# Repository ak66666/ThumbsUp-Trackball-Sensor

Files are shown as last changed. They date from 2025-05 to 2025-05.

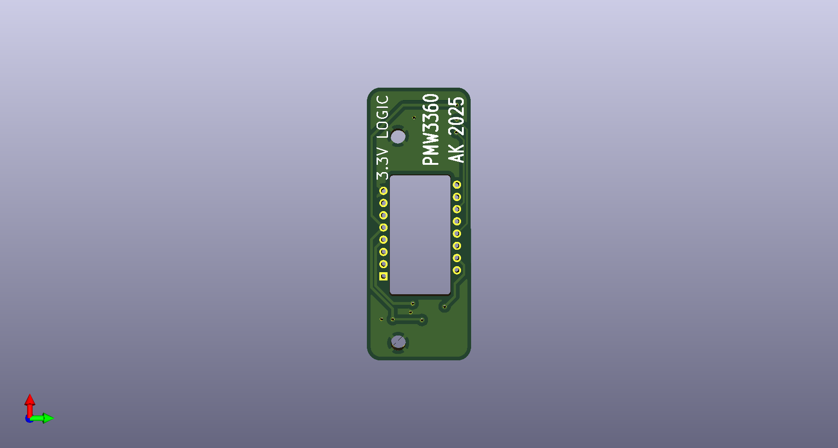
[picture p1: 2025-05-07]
Pictures/PMW3360 Back View.png

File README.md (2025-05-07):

# PMW3360 breakout board

# A clone of https://github.com/jfedor2/pmw3360-breakout

Changes inlclude:
- Layout modified to make the board narrower.
- Connector for a 12 line flexible cable replaced the pin headers.
The rest is practically the same.

This repository contains PCB design files for a breakout board for the PMW3360 optical mouse sensor.

The board doesn't do any level shifting so it only works with 3.3V logic.

The dimensions of the board are 40mm x 15mm, the mounting holes are for M2 screws.

The files in the [fabrication](fabrication) folder can be used to order this board from JLCPCB with SMT assembly. 
The board you get includes everything except the actual sensor. 
If some of the specific components are out of stock, try to find an equivalent with the same package and parameters.

The sensor chip should be soldered on the top side (the side where all the other components are). 
The dot marks pin 1. The optic goes on the bottom side.

//TODO a render of the PCB

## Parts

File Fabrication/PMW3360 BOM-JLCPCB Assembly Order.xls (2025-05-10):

JLCPCB BOM Tool - BOM Matching
BOM name：PMW3360 BOM-JLCPCB Assembly Order.xlsx |  |  | Download Time：2025-05-09 08:33:58 |  |  |  | * Our matching results are updated in real-time, but stock and prices may change. If it's been over 24 hours, please re-match before placing your order.
PCB Assembled Qty：5 |  |  | Est. Total Price：1.0211
Your BOM |  |  |  |  | Matched Parts |  |  |  |  |  |  | Order Information
Top Designator | Bottom Designator | Comment | Footprint | JLCPCB Part # | Matches | Part # | Manufacturer | Footprint | Description | Category | Warning | JLCPCB Part # | Product link | Lib Type | Qty | Source | Total Price ($)
C1 |  | 0.1u | C_0603_1608Metric |  | Select by System | CC0603KRX7R9BB104 | YAGEO | 0603 | 50V 100nF X7R ±10% 0603 Multilayer Ceramic Capacitors MLCC - SMD/SMT ROHS | Multilayer Ceramic Capacitors MLCC - SMD/SMT |  | C14663 | https://jlcpcb.com/partdetail/YAGEO-CC0603KRX7R9BB104/C14663 | Basic | 5 | 5 JLCPCB | 0.012
C2 |  | 1u | C_0603_1608Metric |  | Select by System | CL10A105KB8NNNC | Samsung Electro-Mechanics | 0603 | 50V 1uF X5R ±10% 0603 Multilayer Ceramic Capacitors MLCC - SMD/SMT ROHS | Multilayer Ceramic Capacitors MLCC - SMD/SMT |  | C15849 | https://jlcpcb.com/partdetail/16531-CL10A105KB8NNNC/C15849 | Basic | 5 | 5 JLCPCB | 0.0255
C3 |  | 4.7u | C_0603_1608Metric |  | Select by System | CL10A475KO8NNNC | Samsung Electro-Mechanics | 0603 | 16V 4.7uF X5R ±10% 0603 Multilayer Ceramic Capacitors MLCC - SMD/SMT ROHS | Multilayer Ceramic Capacitors MLCC - SMD/SMT |  | C19666 | https://jlcpcb.com/partdetail/20375-CL10A475KO8NNNC/C19666 | Basic | 5 | 5 JLCPCB | 0.0565
R1 |  | 39 | R_0603_1608Metric |  | Select by System | RC0603FR-0739RL | YAGEO | 0603 | 100mW Thick Film Resistors 75V ±100ppm/℃ ±1% 39Ω 0603 Chip Resistor - Surface Mount ROHS | Chip Resistor - Surface Mount |  | C137733 | https://jlcpcb.com/partdetail/YAGEO-RC0603FR0739RL/C137733 | Extended | 20 | 20 JLCPCB | 0.024
R2 |  | 10k | R_0603_1608Metric |  | Select by System | 0603WAF1002T5E | UNI-ROYAL(Uniroyal Elec) | 0603 | 100mW Thick Film Resistors 75V ±100ppm/℃ ±1% 10kΩ 0603 Chip Resistor - Surface Mount ROHS | Chip Resistor - Surface Mount |  | C25804 | https://jlcpcb.com/partdetail/26547-0603WAF1002T5E/C25804 | Basic | 5 | 5 JLCPCB | 0.005
U2 |  | TCR2EF19 | SOT-23-5 |  | Select by Customer | TLV70018DDCR | Texas Instruments | SOT-23-5 | 68dB@(1kHz) 200mA Fixed 1.8V Positive electrode 5.5V SOT-23-5 Voltage Regulators - Linear, Low Drop Out (LDO) Regulators ROHS | Voltage Regulators - Linear, Low Drop Out (LDO) Regulators | 1.The comment (TLV70018DDCR) of this part does not match the one (TCR2EF19) provided in your BOM. Please confirm; | C79924 | https://jlcpcb.com/partdetail/TexasInstruments-TLV70018DDCR/C79924 | Extended | 7 | 7 JLCPCB | 0.8981

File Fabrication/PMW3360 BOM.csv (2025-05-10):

Designator | Footprint | Quantity | Designation | LCSC
U2 | SOT-23-5 | 1 | TCR2EF19
R2 | R_0603_1608Metric | 1 | 10k | C25804
R1 | R_0603_1608Metric | 1 | 39 | C137733
C3 | C_0603_1608Metric | 1 | 4.7u | C19666
C2 | C_0603_1608Metric | 1 | 1u | C15849
C1 | C_0603_1608Metric | 1 | 0.1u | C14663

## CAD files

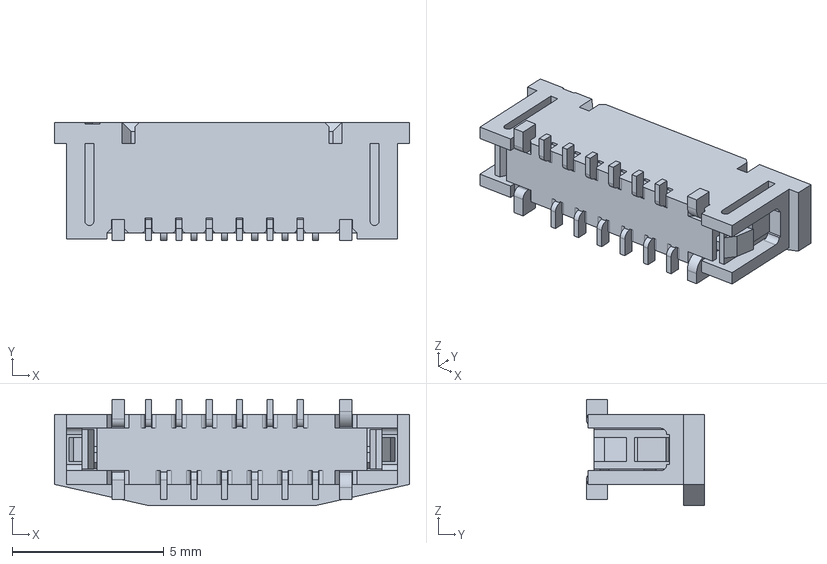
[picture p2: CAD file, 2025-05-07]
Molex 52559-1233/52559-1233/3D/52559-1233.stp
11.7 x 3.90 x 3.50 mm

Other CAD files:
Molex 52559-1233/52559-1233/Allegro/525591233.psm
Molex 52559-1233/52559-1233/DEHDL/52559_1233/chips/chips.prt

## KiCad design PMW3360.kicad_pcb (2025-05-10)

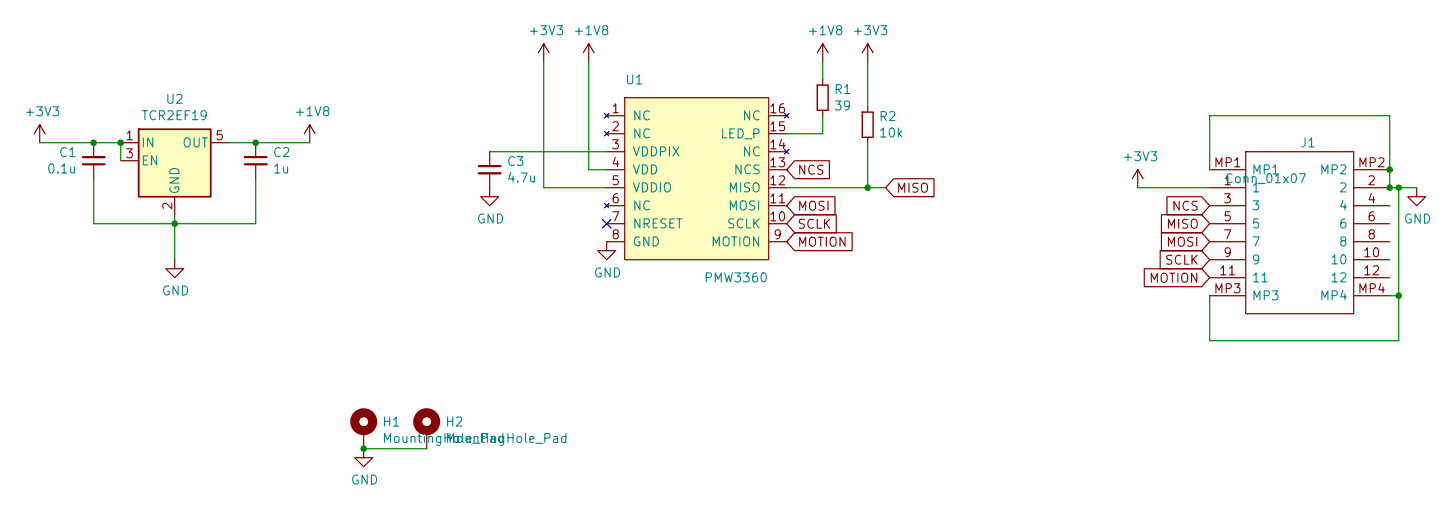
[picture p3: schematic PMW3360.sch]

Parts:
C1: 0.1u; C_0603_1608Metric; LCSC C14663
C2: 1u; C_0603_1608Metric; LCSC C15849
C3: 4.7u; C_0603_1608Metric; LCSC C19666
H1, H2: MountingHole_Pad; MountingHole_2.2mm_M2
J1: Conn_01x07; 525591233; Manufacturer_Part_Number 52559-1233; Mouser Part Number 538-52559-1233
R1: 39; R_0603_1608Metric; LCSC C137733
R2: 10k; R_0603_1608Metric; LCSC C25804
U1: PMW3360
U2: TCR2EF19; SOT-23-5; LCSC C146366

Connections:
+1V8: C2.1, R1.1, U1.4 (VDD), U2.5 (OUT)
+3V3: C1.2, J1.1, R2.1, U1.5 (VDDIO), U2.1 (IN), U2.3 (EN)
GND: C1.1, C2.2, C3.2, H1.1, H2.1, J1.2, J1.MP1, J1.MP2, J1.MP3, J1.MP4, U1.8 (GND), U2.2 (GND)
MISO: J1.5, R2.2, U1.12 (MISO)
MOSI: J1.7, U1.11 (MOSI)
MOTION: J1.11, U1.9 (MOTION)
NCS: J1.3, U1.13 (NCS)
unnamed: C3.1, U1.3 (VDDPIX)
unnamed: R1.2, U1.15 (LED_P)
SCLK: J1.9, U1.10 (SCLK)

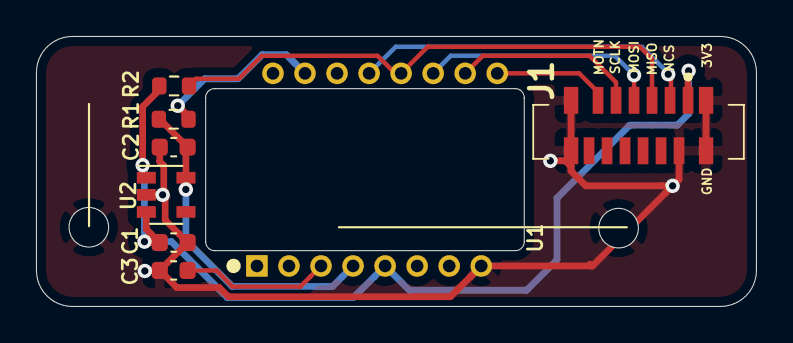
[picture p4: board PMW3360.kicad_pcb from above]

Board: 2 copper layers, 40.0 x 15.0 mm, 10 parts (0 on the bottom side), 10 nets.

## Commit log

2025-05-07 Added a PMW3360 breakout board cloned from jfedor2's original design.
    [52559-1233.stp, 525591233.psm, EDI2CAP.CFG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]
2025-05-07 Added board renders.
    [PMW3360.kicad_pcb]
2025-05-07 Adjusted board edges so it is square and the main measures are rounded.
    [PMW3360.kicad_pcb]
2025-05-10 Corrected the power lines - connected them to the right pins of the sockets.
    [PMW3360 BOM-JLCPCB Assembly Order.xls, PMW3360 BOM.csv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]
